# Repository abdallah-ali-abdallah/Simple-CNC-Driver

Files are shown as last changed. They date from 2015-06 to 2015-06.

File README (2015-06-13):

Simple Dual CNC driver (or 4 DC motors) useing 2 L293 chip

This driver can be used to control 2 Bipolar stepper motors (4 wires motor) or it can be used to control 4 DC motors

Included example cods to run the motors (written in both ANSI-C"ATmeal Studio" and Arduino)

All the files (schematics, PCB) designed by EagleCAD 7.3

Licence: Creative common CC-SA-NC

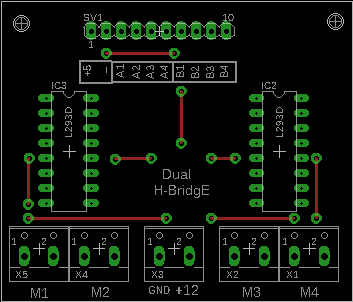
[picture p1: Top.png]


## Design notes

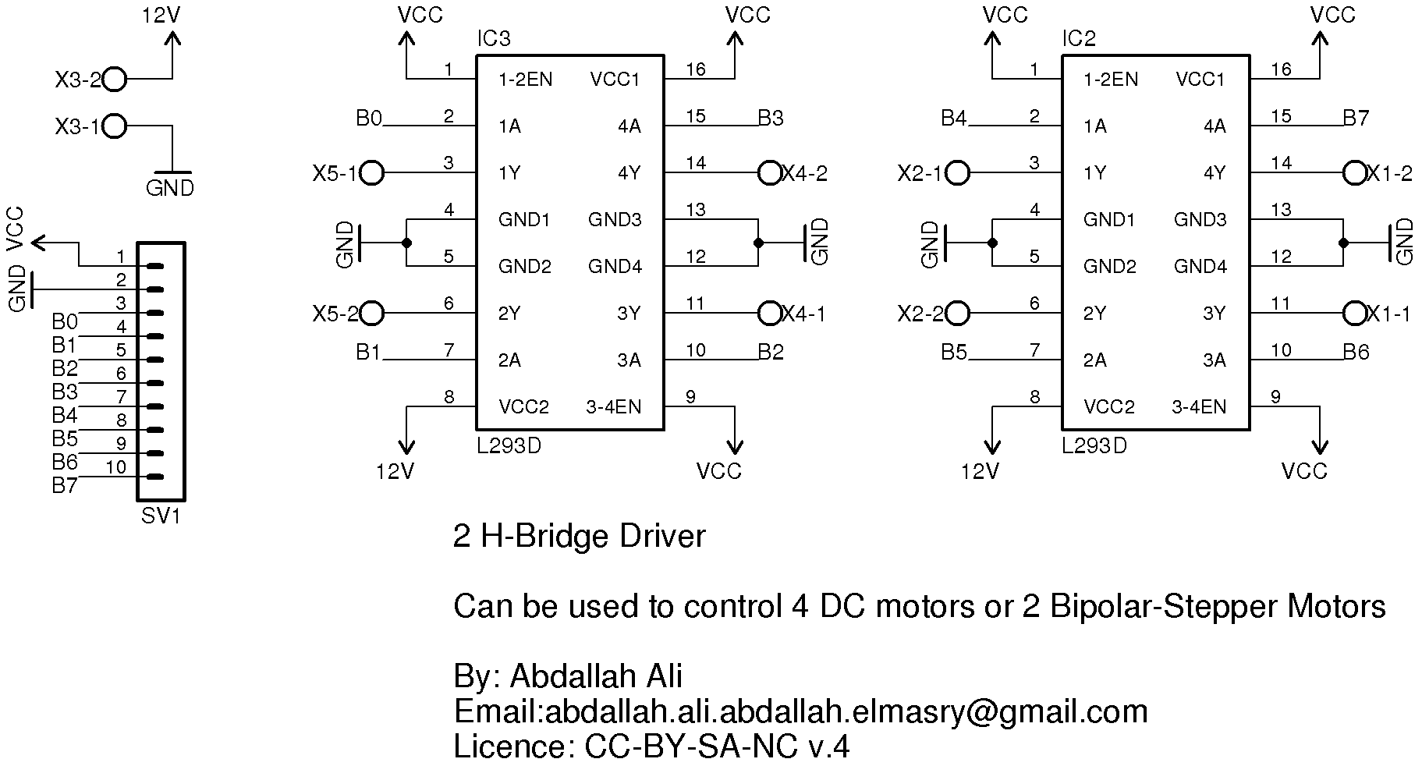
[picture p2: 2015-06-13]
dual-h-bridge-schematic.png

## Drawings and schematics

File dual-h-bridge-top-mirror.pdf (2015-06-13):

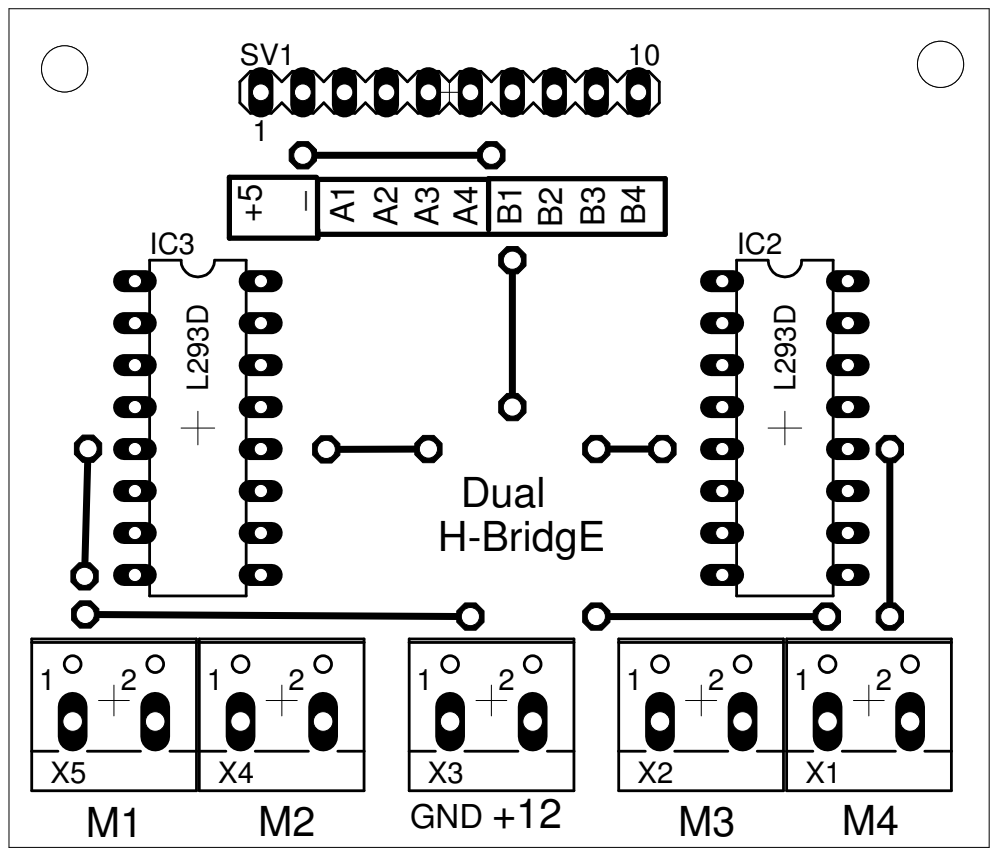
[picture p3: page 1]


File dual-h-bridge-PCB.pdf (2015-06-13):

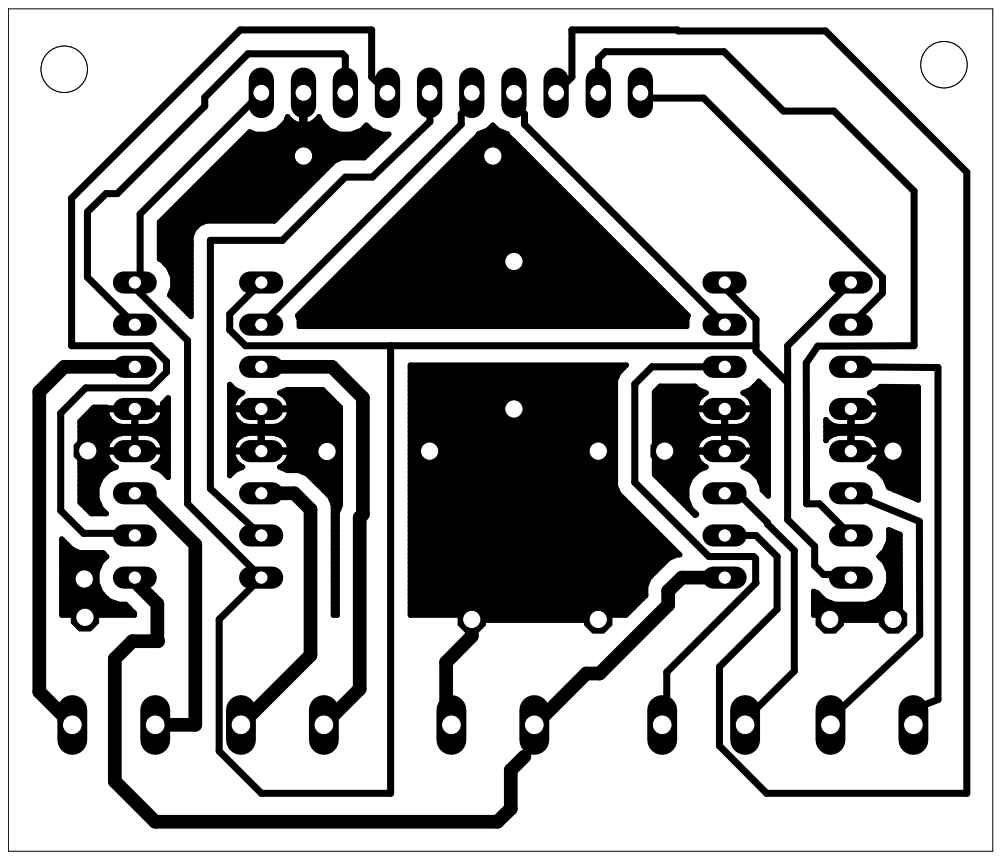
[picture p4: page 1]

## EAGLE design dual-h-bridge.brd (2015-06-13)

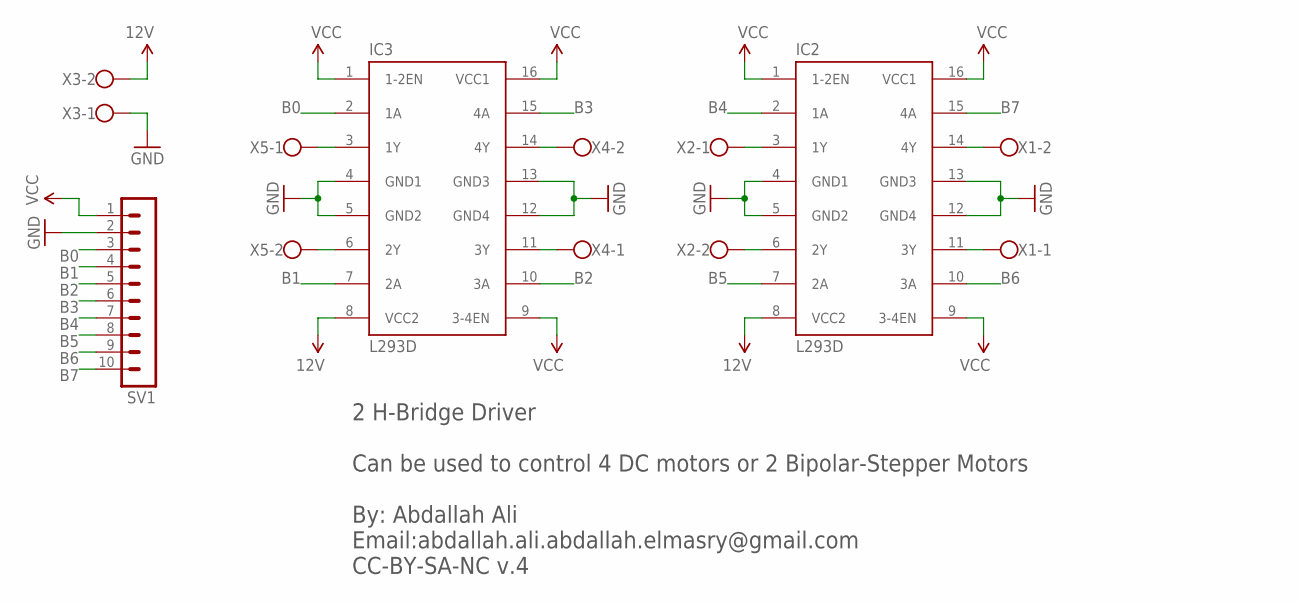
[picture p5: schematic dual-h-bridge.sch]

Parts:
IC2, IC3: L293D; DIL16
SV1: MA10-1
X1, X2, X3, X4, X5: W237-102

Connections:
12V: IC2.8 (VCC2), IC3.8 (VCC2), X3.2
B0: IC3.2 (1A), SV1.3
B1: IC3.7 (2A), SV1.4
B2: IC3.10 (3A), SV1.5
B3: IC3.15 (4A), SV1.6
B4: IC2.2 (1A), SV1.7
B5: IC2.7 (2A), SV1.8
B6: IC2.10 (3A), SV1.9
B7: IC2.15 (4A), SV1.10
GND: IC2.4 (GND1), IC2.5 (GND2), IC2.12 (GND4), IC2.13 (GND3), IC3.4 (GND1), IC3.5 (GND2), IC3.12 (GND4), IC3.13 (GND3), SV1.2, X3.1
unnamed: IC3.3 (1Y), X5.1
unnamed: IC2.3 (1Y), X2.1
unnamed: IC2.6 (2Y), X2.2
unnamed: IC2.11 (3Y), X1.1
unnamed: IC2.14 (4Y), X1.2
unnamed: IC3.6 (2Y), X5.2
unnamed: IC3.11 (3Y), X4.1
unnamed: IC3.14 (4Y), X4.2
VCC: IC2.1 (1-2EN), IC2.9 (3-4EN), IC2.16 (VCC1), IC3.1 (1-2EN), IC3.9 (3-4EN), IC3.16 (VCC1), SV1.1

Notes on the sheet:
2 H-Bridge Driver Can be used to control 4 DC motors or 2 Bipolar-Stepper Motors By: Abdallah Ali Email:abdallah.ali.abdallah.elmasry@gmail.com CC-BY-SA-NC v.4

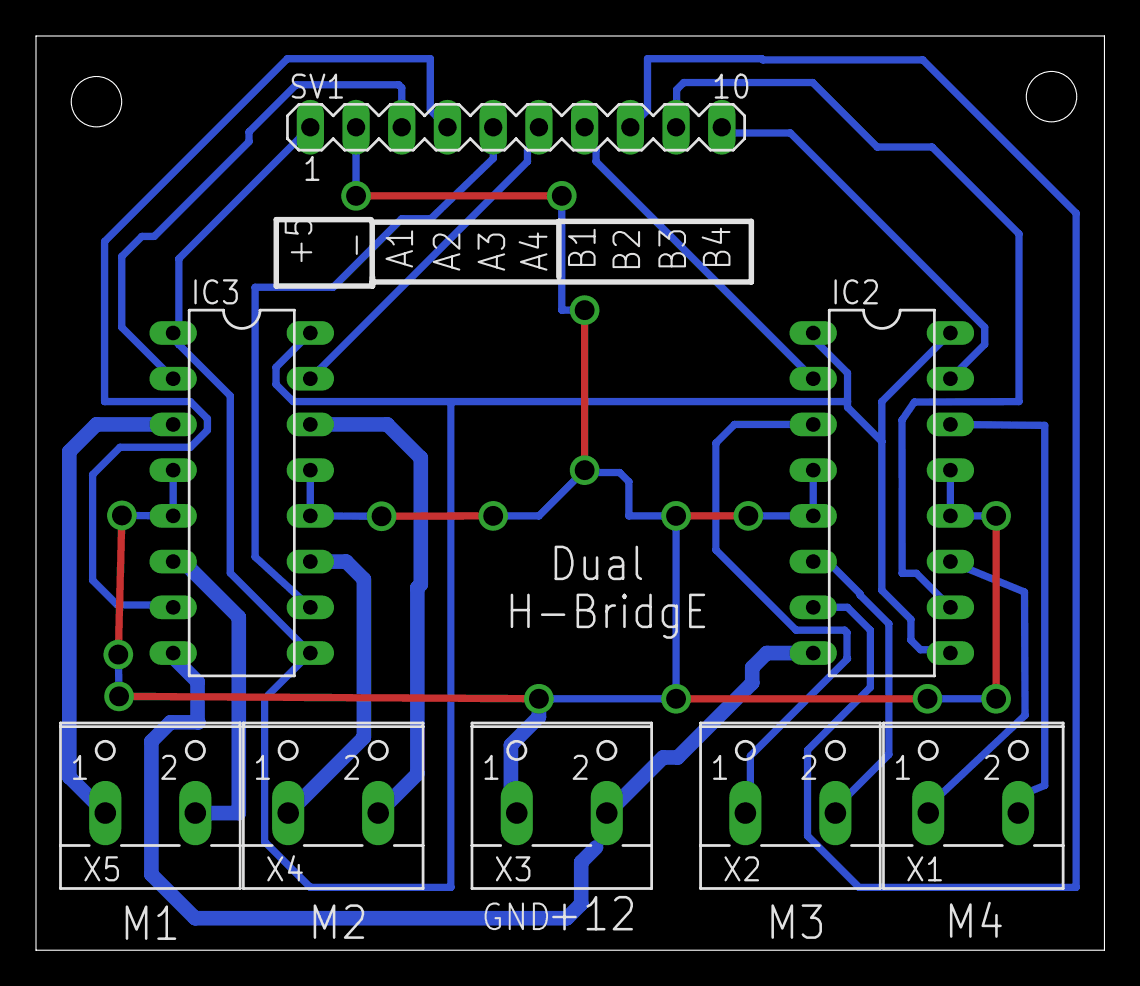
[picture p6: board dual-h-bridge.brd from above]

Board: 2 copper layers, 59.4 x 50.8 mm, 8 parts (0 on the bottom side), 19 nets.

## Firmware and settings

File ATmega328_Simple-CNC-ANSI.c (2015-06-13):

/*
 * Simple CNC V.1.0 - 2 Axis control
 *  
 *   Licennce: CC-BY-SA
 */ 

#define F_CPU 16000000UL				// Define Clock Source 
#define __DELAY_BACKWARD_COMPATIBLE__	// Added to Fix delay.h bug 

#include <avr/io.h>
#include <avr/interrupt.h>
#include <util/delay.h>

// Global Mode to set the mode Start = 0xff ,  Stop = 0x00
volatile uint8_t operationMode = 0x0;

// Global Variable to set the motor speed 
volatile uint8_t motorSpeedDelay;


//Functions Declaration 
void init_ADC();
void init_Interrupt0();
void init_Hbridge();
void y_axis_backward(uint8_t steps_yb);
void y_axis_forward(uint8_t steps_yf);
void x_axis_backward(uint8_t steps_xb);
void x_axis_forward(uint8_t steps_xf);
void shutDownHbridge();

// Main App
int main(void)
{
	init_Hbridge();		// Setup the X-Y motors
	init_Interrupt0();	// Setup INT0
	init_ADC();			// Setup ADC on channel 5
	sei();				// Enable All Interrupts
	
	while(1)
	{	
		while(operationMode == 0xff)
		{
			for(uint8_t i=1;i<=40;i=i+2)
			{
				x_axis_forward(i);
				y_axis_forward(i);
				x_axis_backward(i);
				y_axis_backward(i);
			}
	
		}
	
		
	}
}

ISR(INT0_vect)
{
	operationMode = ~ operationMode;
	
	// Invert the Operation Mode
}

ISR(ADC_vect)
{
	motorSpeedDelay = ADCH * 2;		// Set the delay value from 0 to 512 ms
	ADCSRA |= (1<<ADSC);			// Restart the ADC conversion
}

void init_Hbridge()
{
	DDRC |= (1<<PC0)|(1<<PC1)|(1<<PC2)|(1<<PC3);	// First  Motor control pins
	DDRB |= (1<<PB2)|(1<<PB3)|(1<<PB4)|(1<<PB5);	// Second Motor control pins
}

void init_Interrupt0()
{	
	// Set the interrupt on the LOW level
	DDRD &= ~(1<<PD2);
	PORTD |= (1<< PD2);		//Enable Pull up for INT0 (PD2)
	EIMSK |= (1<<INT0);		//Enable INT0 interrupt
}

void init_ADC()
{
	// The ADC will capture the the potentiometer voltage to calculate the motor Speed
	// ADC will work in 8 bit Mode (left Adjusted)
	ADCSRA |= (1<<ADEN);							// Enable ADC
	ADCSRA |= (1<<ADPS0) | (1<<ADPS1) | (1<<ADPS2); // Set ADC Clk to the slowest conversion rate
	ADMUX  |= (1<<MUX0) | (1<<MUX2);				// Choose channel 5 
	ADMUX  |= (1<<REFS0);							// Use AVCC as AREF
	ADMUX  |= (1<<ADLAR);							// 8 bit mode (left adjusted)
	ADCSRA |= (1<<ADIE);							// Enable ADC interrupter
	ADCSRA |= (1<<ADSC);							// Start the First conversion  
}


void x_axis_forward (uint8_t steps_xf)
{

	uint8_t  i ;

	for ( i=0 ; i <= steps_xf; i++ )
	{
		if(operationMode == 0) break;	  // This line used to stop the stepper immediately
		PORTC = 0b00000110 ;              // stepper motor rotation degree = 90
		_delay_ms(motorSpeedDelay);      //stop the motor for the value captured from the potentiometer (waiting time until the next step)
	
		if(operationMode == 0) break;
		PORTC = 0b00000101 ;              // stepper motor rotation degree =180
		_delay_ms(motorSpeedDelay);      //stop the motor for the value captured from the potentiometer (waiting time until the next step)

		if(operationMode == 0) break;
		PORTC = 0b00001001 ;              // stepper motor rotation degree =270
		_delay_ms(motorSpeedDelay);      //stop the motor for the value captured from the potentiometer (waiting time until the next step)

		if(operationMode == 0) break;
		PORTC = 0b00001010 ;              // stepper motor rotation degree =360
		_delay_ms(motorSpeedDelay);      //stop the motor for the value captured from the potentiometer (waiting time until the next step)
	}
}


void x_axis_backward (uint8_t steps_xb)
{
	
	uint8_t i ;
	for (i=0 ; i<= steps_xb ; i++)
	{
		if(operationMode == 0) break;
		PORTC = 0b00001010 ;              // stepper motor rotation degree =90
		_delay_ms(motorSpeedDelay) ;     //stop the motor for the value captured from the potentiometer (waiting time until the next step)

		if(operationMode == 0) break;
		PORTC = 0b00001001 ;              // stepper motor rotation degree =180
		_delay_ms(motorSpeedDelay) ;     //stop the motor for the value captured from the potentiometer (waiting time until the next step)
		
		if(operationMode == 0) break;
		PORTC = 0b00000101 ;              // stepper motor rotation degree =270
		_delay_ms(motorSpeedDelay) ;     //stop the motor for the value captured from the potentiometer (waiting time until the next step)

		if(operationMode == 0) break;
		PORTC = 0b00000110 ;               // stepper motor rotation degree =360
		_delay_ms(motorSpeedDelay) ;     //stop the motor for the value captured from the potentiometer (waiting time until the next step)
	}
}



void y_axis_forward (uint8_t steps_yf)
{
	
	uint8_t i ;
	for  (i=0 ; i<= steps_yf ; i++)
	{
		if(operationMode == 0) break;
		PORTB = 0b00011000;              // stepper motor rotation degree =90
		_delay_ms(motorSpeedDelay) ;     //stop the motor for the value captured from the potentiometer (waiting time until the next step)
		
		if(operationMode == 0) break;
		PORTB = 0b00010100;              // stepper motor rotation degree =180
		_delay_ms(motorSpeedDelay) ;     //stop the motor for the value captured from the potentiometer (waiting time until the next step)
		
		if(operationMode == 0) break;
		PORTB = 0b00100100;              // stepper motor rotation degree =270
		_delay_ms(motorSpeedDelay) ;     //stop the motor for the value captured from the potentiometer (waiting time until the next step)
		
		if(operationMode == 0) break;
		PORTB = 0b00101000;              // stepper motor rotation degree =360
		_delay_ms(motorSpeedDelay) ;     //stop the motor for the value captured from the potentiometer (waiting time until the next step)
	}
}

void y_axis_backward (uint8_t steps_yb)
{
	
	uint8_t i;
	
	for (i=0 ; i<=steps_yb ; i++)
	{	
		if(operationMode == 0) break;
		PORTB = 0b00101000;              // stepper motor rotation degree =90
		_delay_ms(motorSpeedDelay) ;     //stop the motor for the value captured from the potentiometer (waiting time until the next step)
		
		if(operationMode == 0) break;
		PORTB = 0b00100100;                // stepper motor rotation degree =180
		_delay_ms(motorSpeedDelay) ;     //stop the motor for the value captured from the potentiometer (waiting time until the next step)
		
		if(operationMode == 0) break;
		PORTB = 0b00010100;              // stepper motor rotation degree =270
		_delay_ms(motorSpeedDelay) ;     //stop the motor for the value captured from the potentiometer (waiting time until the next step)
		
		if(operationMode == 0) break;
		PORTB = 0b00011000;              // stepper motor rotation degree =360
		_delay_ms(motorSpeedDelay) ;     //stop the motor for the value captured from the potentiometer (waiting time until the next step)
	
	}
}


void shutDownHbridge()
{
	PORTC &= ~((1<<PC0)|(1<<PC1)|(1<<PC2)|(1<<PC3));	// Shutdown stepper Motor 1 control pins
	PORTB &= ~((1<<PB2)|(1<<PB3)|(1<<PB4)|(1<<PB5));	// Shutdown stepper Motor 2 control pins
}

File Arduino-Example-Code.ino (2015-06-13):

// Arduino Example Code to operate 1 Stepper Motor connected to B0 - B1 - B2 - B3 
// declaration of PINS that connected the wire to motor

int B0 = 13;
int B1 = 12;
int B2 = 11;
int B3 = 10;

//this is the time to wait in every single step, which control the speed 
int delayTime = 100;

//set the pin for OUTPUT
void setup() 
{
  pinMode(B0, OUTPUT);
  pinMode(B1, OUTPUT);
  pinMode(B3, OUTPUT);
  pinMode(B2, OUTPUT);
}

void loop() 
{
  forward(13);
  delay(500);
  backward(13);
}

void forward(int steps)
{
  for(int i=0;i<steps;i++)
  {
// in every phase 2 wires is up and 2 is down
    digitalWrite(B0, LOW);
    digitalWrite(B1, HIGH);
    digitalWrite(B2, HIGH);
    digitalWrite(B3, LOW);
    delay(delayTime);
 
    digitalWrite(B0, LOW);
    digitalWrite(B1, HIGH);
    digitalWrite(B2, LOW);
    digitalWrite(B3, HIGH);
    delay(delayTime);
 
    digitalWrite(B0, HIGH);
    digitalWrite(B1, LOW);
    digitalWrite(B2, LOW);
    digitalWrite(B3, HIGH);
    delay(delayTime);
 
    digitalWrite(B0, HIGH);
    digitalWrite(B1, LOW);
    digitalWrite(B2, HIGH);
    digitalWrite(B3, LOW);
    delay(delayTime);}
}

void backward (int steps)
{
  for(int i=0;i<steps;i++)
  {
    digitalWrite(B0, HIGH);
    digitalWrite(B1, LOW);
    digitalWrite(B2, HIGH);
    digitalWrite(B3, LOW);
    delay(delayTime);
 
    digitalWrite(B0, HIGH);
    digitalWrite(B1, LOW);
    digitalWrite(B2, LOW);
    digitalWrite(B3, HIGH);
    delay(delayTime);
 
     digitalWrite(B0, LOW);
     digitalWrite(B1, HIGH);
     digitalWrite(B2, LOW);
     digitalWrite(B3, HIGH);
     delay(delayTime);
 
     digitalWrite(B0, LOW);
     digitalWrite(B1, HIGH);
     digitalWrite(B2, HIGH);
     digitalWrite(B3, LOW);
     delay(delayTime);
  }

}

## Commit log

2015-06-13 Schematic File - EagleCAD 7.3
    [dual-h-bridge.sch]
2015-06-13 PCB file - EagleCAD 7.3
    [dual-h-bridge.brd]
2015-06-13 Bottom layer - printable file using toner tansfer methode
2015-06-13 Schematics in PNG formate
2015-06-13 Arduino Example Code

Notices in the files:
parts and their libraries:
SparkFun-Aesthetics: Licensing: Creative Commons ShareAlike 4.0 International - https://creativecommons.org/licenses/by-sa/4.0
